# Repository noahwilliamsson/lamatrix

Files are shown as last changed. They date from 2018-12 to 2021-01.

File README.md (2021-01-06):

<!-- START doctoc generated TOC please keep comment here to allow auto update -->
<!-- DON'T EDIT THIS SECTION, INSTEAD RE-RUN doctoc TO UPDATE -->
**Table of Contents**  *generated with [DocToc](https://github.com/thlorenz/doctoc)*

- [Animated LED matrix display](#animated-led-matrix-display)
    - [Building and deploying the MCU](#building-and-deploying-the-mcu)
        - [MicroPython](#micropython)
        - [Arduino](#arduino)
    - [Hardware](#hardware)
        - [LED matrix display](#led-matrix-display)
        - [MCUs](#mcus)
            - [WiPy 3.0 pinout](#wipy-30-pinout)
            - [Teensy 3.1/3.2 pinout](#teensy-3132-pinout)
        - [Raspberry Pi](#raspberry-pi)
    - [Wiring things up](#wiring-things-up)
        - [LED matrix](#led-matrix)
        - [Button](#button)
        - [Connecting second UART on Pycom module to Raspberry Pi](#connecting-second-uart-on-pycom-module-to-raspberry-pi)
        - [Remote power management for Raspberry Pi](#remote-power-management-for-raspberry-pi)
    - [Hacking](#hacking)
        - [On the serial protocol](#on-the-serial-protocol)
    - [Running the Python scripts](#running-the-python-scripts)
    - [Configuring the Raspberry Pi](#configuring-the-raspberry-pi)
        - [Optional steps](#optional-steps)
- [Credits](#credits)

<!-- END doctoc generated TOC please keep comment here to allow auto update -->

# Animated LED matrix display

This is a project to drive a 32x8 or 16x16 LED matrix based on the popular WS2812 RGB LEDs using a microcontroller running [MicroPython](https://micropython.org).  There is experimental support for allowing a more powerful host computer (e.g. a Raspberry Pi Zero W) to remotely control a microcontroller without WiFi (e.g. a Teensy 3.x) and the display connected to it over USB serial.  Low FPS video of a standalone Pycom LoPy 1 development board cycling through the scenes:

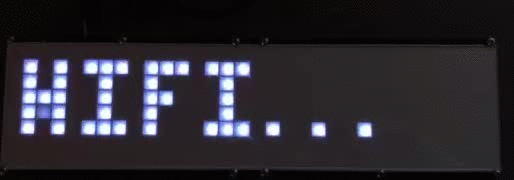
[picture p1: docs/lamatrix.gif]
LED matrix animated


Static picture with clock scene.  For some reason the colors aren't captured as vidvid as they are in real life.

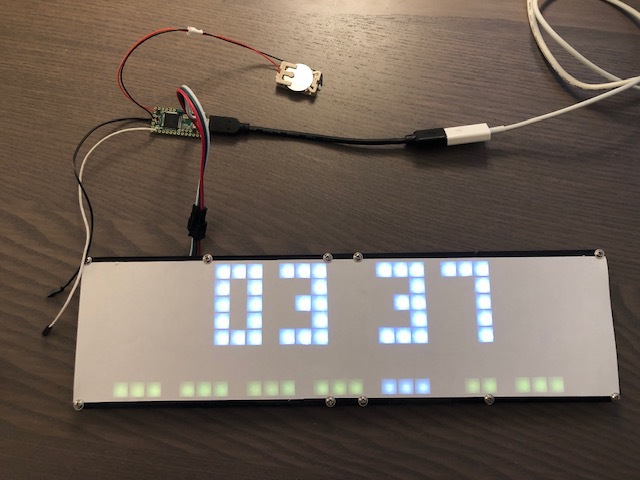
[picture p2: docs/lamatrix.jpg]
LED matrix with clock scene


Features:

- clock (time, date and weekday)
- weather
- random animations
- button inputs
- [config](config.json) file in JSON
- multiple WiFi networks can be configured

Primary development has been made on [Pycom](https://www.pycom.io)'s development boards, including the (obsolete) LoPy 1 and the newer WiPy 3.  There is also an Arduino [sketch](ArduinoSer2FastLED/ArduinoSer2FastLED.ino) for Teensy 3.1/3.2 boards that implements a custom serial protocol that is spoken by the host software ([main.py](main.py) and [arduinoserialhal.py](arduinoserialhal.py)) that allows the LED matrix to be remotely controlled.

**Update 2021**: If you want to use this with a Raspberry Pi instead of an MCU running MicroPython, see the issue [Using Raspberry PI directly to 8 x 32 not working?](https://github.com/noahwilliamsson/lamatrix/issues/1).

## Building and deploying the MCU

### MicroPython

[Connect](https://docs.pycom.io/gettingstarted/connection/) your Pycom module to your computer via USB (or 3.3v serial).  Open a serial connection to the module and [configure WiFi](https://docs.pycom.io/tutorials/all/wlan.html) in the REPL like this:

    from network import WLAN
    wlan = WLAN(mode=WLAN.STA)
    wlan.connect('yourSSID', auth=(WLAN.WPA2, 'yourPassword'))

Connect to the Pycom module's [native FTP server](https://docs.pycom.io/gettingstarted/programming/ftp.html) and login with `micro` / `python`.

Update [config.json](config.json) with your wireless SSID and password.

Upload the following files to `/flash`:

- [config.json](config.json)
- [main.py](main.py)

Upload the following files to `/flash/lib`:

- [animationscene.py](animationscene.py)
- [bootscene.py](bootscene.py)
- [clockscene.py](clockscene.py)
- [demoscene.py](demoscene.py)
- [firescene.py](firescene.py)
- [weatherscene.py](weatherscene.py)
- [icon.py](icon.py)
- [ledmatrix.py](ledmatrix.py)
- [pycomhal.py](pycomhal.py)
- [renderloop.py](renderloop.py)
- [urequests.py](urequests.py) (needed by `weatherscene.py`)
- [ws2812.py](ws2812.py) (needed by `pycomhal.py`)

Create a new directory under `/flash/icons` and upload any animation icons referenced in [config.json](config.json) (see [icons/README.md](icons/README.md) for details).

Create a new directory under `/flash/weather` and upload animated weather icons (see [weather/README.md](weather/README.md) for details).

Next, you'll want to read [Wiring things up](#wiring-things-up).

### Arduino

The host-side Python code expects to be able to talk to the microcontroller over a serial protocol (running on top of USB serial).  Software that speaks this special protocol and can talk to the LED matrix needs to be loaded onto the microcontroller.

Assuming you have an MCU which is supported by Arduino, try:

1. Download the latest version of Arduino
2. In the _Library manager_, found via the menu entry _Tools > Manage Libraries..._, search for `fastled` and install the package
3. If you have a Teensy 3.x MCU, install the Arduino software add-on Teensyduino from https://www.pjrc.com/teensy/td_download.html
4. Connect the MCU to your computer using an USB cable
5. Open the Arduino sketch (project)
6. Setup the board under the _Tools_ menu, e.g. for a Teensy board:
  - Board: `Teensy 3.2 / 3.1`
  - Port: `/dev/tty.usbmodem575711` (exact path might depend on the specific board and OS)
7. Build (compile) the sketch via the menu entry _Sketch > Verify/Compile_
8. Upload the newly built sketch to the MCU via the menu entry _Sketch > Upload_

## Hardware

### LED matrix display

On popular auction sites there are 8x8, 8x32 and 16x16 flexible LED matrix displays with WS2812 LEDs if you search for e.g. `LED Matrix WS2812 5050 flexible`:

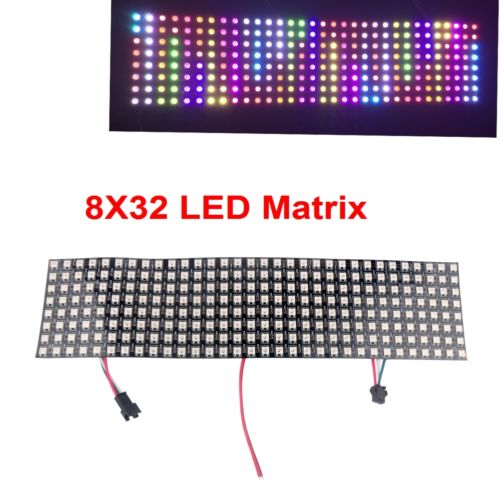
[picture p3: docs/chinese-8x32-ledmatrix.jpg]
.

Price: €35-45

For the 8x32 variant, you can 3D print a frame from these objects:

- [32x8 LED Matrix grid for diffuser](https://www.thingiverse.com/thing:1903744)
- [3d-parts/lamatrix.scad](3d-parts/lamatrix.scad) (customize it in [OpenSCAD](https://www.openscad.org/downloads.html), hit Render (F6) and export it as STL)

For diffusing the light emitted by the LEDS a paper works suprisingly well if it's tightly held to the grid.

### MCUs

- [WiPy 3.0](https://pycom.io/product/wipy-3-0/) and an [Expansion Board 3.0](https://pycom.io/product/expansion-board-3-0/) for easy programming via USB
  - ESP-32 platform, 520kBytes SRAM + 4MBytes (external) pSRAM, 8MBytes flash, 802.11b/g/n 16Mbps WiFi
  - Price: €20-25
  - Docs and pinout: https://docs.pycom.io/datasheets/development/wipy3
  - Expansion Board (€20-25) docs: https://docs.pycom.io/datasheets/boards/expansion3
- [https://www.pjrc.com/teensy/](Teensy) (for Teensy 3.1/3.2, solder a 32.768kHz crystal to allow for [time-keeping via a battery](https://www.pjrc.com/teensy/td_libs_Time.html))
  - Teensy 3.2: ARM Cortex-M4 72MHz, 64kBytes SRAM, 256kBytes flash, RTC (requires 32kHz crystal and a 3V battery)
  - Price: €20-25
  - Specs and pinout: https://www.pjrc.com/teensy/teensyLC.html

Both alternatives support both Arduino and MicroPython.

NOTE: it seems that hardware flow control between pyserial and the Pycom modules (e.g. WiPy, LoPy) doesn't work properly for some reason.  This results in the host overwhelming the microcontroller with data, leading to data loss in the serial protocol which in turn messes up what is displayed on the LED matrix.  The Teensy 3.x boards work without problems however.

#### WiPy 3.0 pinout

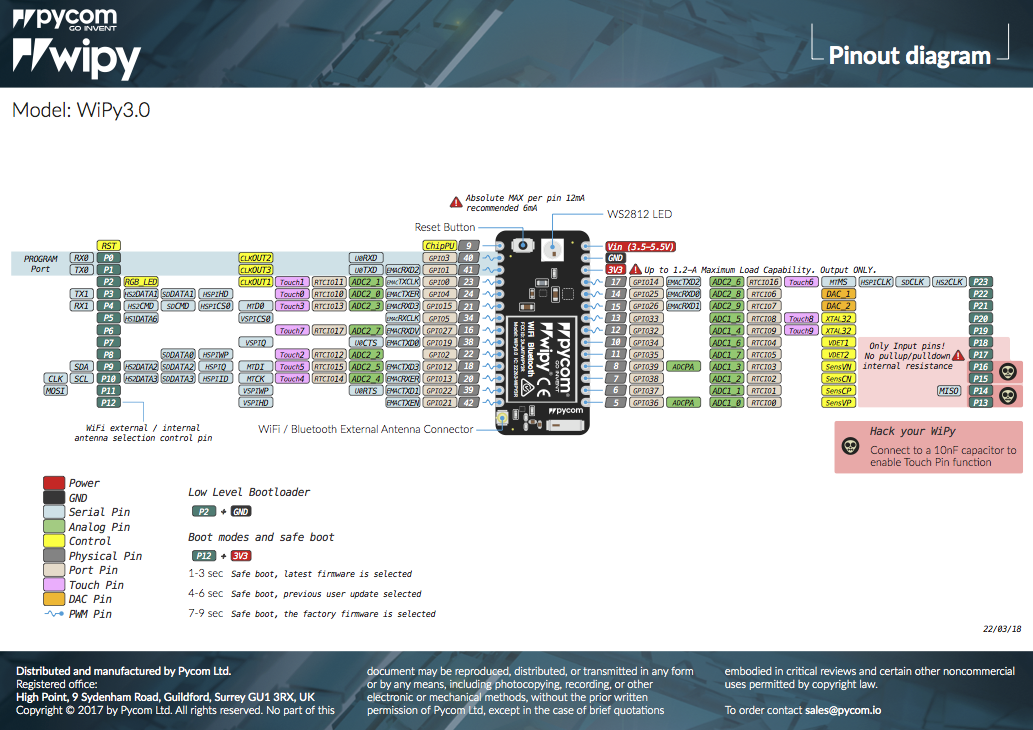
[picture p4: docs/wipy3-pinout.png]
WiPy 3.0 pinout


Source: https://docs.pycom.io/datasheets/development/wipy3.html

#### Teensy 3.1/3.2 pinout

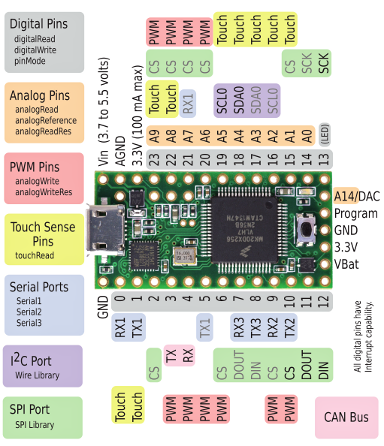
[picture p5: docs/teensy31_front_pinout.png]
Teensy 3.1/3.2 pinout


Source: https://www.pjrc.com/teensy/teensyLC.html

### Raspberry Pi

Newer Raspberry Pi computers have a non-populated RUN pin (marked with a square) that, if tied to ground, will reset the Pi's CPU.  See this answer on [What are the RUN pin holes on Raspberry Pi 2?](https://raspberrypi.stackexchange.com/questions/29339/what-are-the-run-pin-holes-on-raspberry-pi-2/33945#33945).

Since there is a 10k pull-up resistor connected to this pin, the Pi will turn on again when this pin is no longer tied to ground.  The drawback is of course that resetting the CPU leads to an unclean shutdown of the Pi, which in turn might lead to SD card corruption.

A Raspberry Pi which has previously been shutdown using e.g. `sudo poweroff` can be brought back to life by temporarily grounding GPIO 5 (a.k.a BCM 3 a.k.a SCL).  With the help of a small Python script running in the background we can make GPIO 5 an input pin and watch for level changes.  If this pin becomes LOW (i.e. tied to ground) we can initiate a clean shutdown with `sudo systemctl poweroff --force`.

Example from [raspberry-pi/gpio-shutdown.py](raspberry-pi/gpio-shutdown.py):

```python
#!/usr/bin/python
#
# Watch the board pin number 5 for level changes and initiate a power-off
# when this pin goes low.
#
from RPi import GPIO
from subprocess import call

# https://pinout.xyz/pinout/i2c
pin = 5  # a.k.a BCM 3 a.k.a SCL

GPIO.setmode(GPIO.BOARD)
GPIO.setup(pin, GPIO.IN)
GPIO.wait_for_edge(pin, GPIO.FALLING)
print('GPIO 5 dropped to low, initiating poweroff')
call(["/bin/systemctl","poweroff","--force"])
```

## Wiring things up

To the extent possible I've attempted to choose the same set of board pins on both MCUs (microcontrollers).

A short note on pin mappings:

- physical pin numbering refer to the chip's physical pins
- GPIO pin number refer to the chip's internal GPIO pin numbering (e.g. `GPIO22` as shown in pinout mappings)
- board pin numbering refer to the pins as made available on the PCB, with pin 0 or 1 often being in the top left corner after excluding any power/ground/reset pins
- pin ID as mapped in firmware, e.g. _digital pin_ number 10 or _P10_ (as shown in pinout mappings)

### LED matrix

Connect the display like this:

    LED matrix:  5V --> MCU: Vin pin (voltage in)
    LED matrix: GND --> MCU: GND pin
    LED matrix: DIN --> MCU: digital pin 6 on Teensy; P11 (a.k.a GPIO22) on Pycom module

### Button

Connect the buttons like this:

    Left button pin 1 --> MCU: digital pin 9 on Teensy; P9 (a.k.a. GPIO21) pin on Pycom module
    Left button pin 2 --> MCU: GND pin
    Right button pin 1 --> MCU: digital pin 10 on Teensy; P10 (a.k.a. GPIO13) pin on Pycom module
    Right button pin 2 --> MCU: GND pin

### Connecting second UART on Pycom module to Raspberry Pi

To connect the Pycom module's (e.g. WiPy) second UART (3.3V serial port) to the Raspberry Pi's UART, connect:

    Raspberry Pi: board pin  8 (TXD) --> MCU: P4 (a.k.a RX1 a.k.a GPIO15) on Pycom module
    Raspberry Pi: board pin 10 (RXD) --> MCU: P3 (a.k.a TX1 a.k.a GPIO4) on Pycom module
    Raspberry Pi: board pin  6 (GND) --> MCU: GND pin

NOTE: Raspberry Pi modules with built-in WiFi/Bluetooth needs the following line in `/boot/config.txt` to [free up the TXD/RXD pins](https://www.raspberrypi.org/documentation/configuration/uart.md):

    dtoverlay=pi3-disable-bt

Running `screen /dev/serial0 115200` on the Raspberry Pi should now allow you to see data sent from the MCU's second UART.

### Remote power management for Raspberry Pi

To let the MCU manage the Raspberry Pi's power, connect:

    Raspberry Pi: board pin 5 (a.k.a SCL) --> MCU: digital pin 8 on Teensy; P8 (a.k.a GPIO2) on Pycom module
    Raspberry Pi: board pin 6 (a.k.a GND) --> MCU: GND pin

## Hacking

In short:

- everything starts in [main.py](main.py)
- after initializing things, `main.py` hands over control to [renderloop.py](renderloop.py) which consumes _scenes_ (e.g. a [clock](clockscene.py) scene, a [weather](weatherscene.py) scene, ..)
- a framebuffer wrapper around the LED matrix display is in [ledmatrix.py](ledmatrix.py)
- the framebuffer wrapper does low-level display operations via a HAL (hardware abstraction layer)
  - on the host-side this is implemented in [arduinoserialhal.py](arduinoserialhal.py)
  - on the host-side this file pretty much opens a serial port and speaks a custom protocol to command the microcontroller to do things
- on the microcontroller-side the custom protocol is implemented in:
  - [ArduinoSer2FastLED.ino](ArduinoSer2FastLED/ArduinoSer2FastLED.ino) for devices running Arduino
  - [pycomhal.py](pycomhal.py) for Pycom devices running MicroPython

To add a new scene, create a Python module (e.g. `demoscene.py`) like this:

```python
from pixelfont import PixelFont

class DemoScene:
    """This module implements an example scene with a traveling pixel"""

    def __init__(self, display, config):
        """
        Initialize the module.
        `display` is saved as an instance variable because it is needed to
        update the display via self.display.put_pixel() and .render()
        """
        self.display = display
        self.intensity = 32
        self.x_pos = 0
        self.text = 'example'
        if not config:
            return
        if 'intensity' in config:
            self.intensity = int(round(config['intensity']*255))

    def reset(self):
        """
        This method is called before transitioning to this scene.
        Use it to (re-)initialize any state necessary for your scene.
        """
        self.x_pos = 0
        print('DemoScene: here we go')

    def input(self, button_state):
        """
        Handle button input
        """
        print('DemoScene: button state: {}'.format(button_state))
        return 0  # signal that we did not handle the input

    def set_intensity(self, value=None):
        if value is not None:
            self.intensity -= 1
            if not self.intensity:
                self.intensity = 16
        return self.intensity

    def render(self, frame, dropped_frames, fps):
        """
        Render the scene.
        This method is called by the render loop with the current frame number,
        the number of dropped frames since the previous invocation and the
        requested frames per second (FPS).
        """

        if (frame % fps) == 0:
            # Only update pixel once every second
            return True

        display = self.display
        intensity = self.intensity

        dot_x, dot_y = self.x_pos, 0
        text_x, text_y = 2, 2
        color = intensity
        display.clear()
        display.put_pixel(dot_x, dot_y, color, color, color >> 1)
        display.render_text(PixelFont, self.text, text_x, text_y, self.intensity)
        display.render()

        self.x_pos += 1
        if self.x_pos == display.columns:
            return False   # signal that our work is done

        return True   # we want to be called again
```

Then open [main.py](main.py) and locate the following line:

```python
r = RenderLoop(display, config)
```

Below it, create an instance of your module and call `RenderLoop.add_scene()` to add it to the list of scenes.  If your module is named `demoscene.py` and implements the `DemoScene` class it should look something like this:

```python
if 'Demo' in config:
    from demoscene import DemoScene
    scene = DemoScene(display, config['Demo'])
    r.add_scene(scene)
```

You should also add a `"Demo": {},` block to the config file `config.json`.  Store any settings your scene needs here.

With these steps completed, the scene's `render()` method should now eventually be called when you run the host-side software (e.g. `python main.py`).  The method should return `True` until you're ready to hand over control to the next scene, in which case you signal this by returning `False`.

### On the serial protocol

Because of the limited amount of memory available on MCU it was initially decided to use a more powerful computer to render things on the LED matrix display.  The most natural way of connecting a MCU and a host computer is to use the serial interface available on many popular MCUs, and thus a serial protocol was born.

To add new functionality to the serial protocol, ensure that you make the necessary updates in:

- the MCU implementation on the Arduino side, in and around `loop()`
- the MCU implementation on the MicroPython side, in `pycomhal.py`
- the host computer implementation, in `arduinoserialhal.py`

## Running the Python scripts

For Debian/Ubuntu derived Linux systems, try:

```bash
sudo apt install -y python-requests python-serial
```

On macOS, install pyserial (macOS already ships the requests module):

```bash
sudo -H easy_install serial
```

NOTE: There are known issues with hardware flow control and the driver/chip used in the Pycom modules (e.g. WiPy, LoPy).  This causes the host side scripts to overwhelm the microcontroller with data.  There do not appear to be any such issues with the Teensy on macOS.  There are no known issues with either module with recent Linux distributions, including Raspbian.

Connect the LED matrix to the microcontroller and then connect the microcontroller to your computer (via USB).  You should now be able to command the microcontroller to drive the display with:

```bash
python main.py
```

NOTES:

- The animation scene expects animated icons from a third-party source.  See the [icons/README.md](icons/README.md) for details on how to download them.
- The weather scene expects animated icons from a third-party source.  See the [weather/README.md](weather/README.md) for details on how to download them.

## Configuring the Raspberry Pi

If you want to run the Python scripts on the Raspberry Pi, install the necessary Python packages:

```bash
sudo apt install -y python-requests python-serial
# On Raspberry Pi Zero importing the Python `requests` package takes 20+ seconds
# if the python-openssl package is installed (default on Raspbian).
# https://github.com/requests/requests/issues/4278
#
# Uninstall it to speed up loading of `weatherscene.py`
sudo apt purge -y python-openssl
```

Install the support files:

- copy [gpio-shutdown.service](raspberry-pi/gpio-shutdown.service) into `/etc/systemd/system/`
- copy [lamatrix.service](raspberry-pi/lamatrix.service) into `/etc/systemd/system/`

Assuming you've cloned this repo at `/home/pi/lamatrix`, proceed as follows:

```bash
sudo apt install -y python-requests python-serial
cd ~/lamatrix

mkdir -p icons weather
# Download animated icons per the instructions in icons/README.md
# Download animated weather icons per the instructions in icons/README.md

# Install and start services
chmod +x main.py raspberry-pi/gpio-shutdown.py
sudo cp raspberry-pi/gpio-shutdown.service /etc/systemd/system
sudo cp raspberry-pi/lamatrix.service /etc/systemd/system
sudo systemctl daemon-reload
sudo systemctl enable gpio-shutdown.service lamatrix.service
sudo systemctl start gpio-shutdown.service lamatrix.service
```

NOTE: If you're not running under the `pi` user or have placed the files somewhere else than `/home/pi/lamatrix` you will have to update the `ExecPath=`, `User=` and `Group=` attributes in the `.service` files accordingly.

Your Raspberry Pi will now poweroff when board pin number 5 (a.k.a BCM 3 a.k.a SCL) goes LOW (e.g. is temporarily tied to ground).  The shutdown process takes 10-15 seconds.  The Pi can be powered up by again temporarily tying the pin to ground again.

To actually make use of the remote shutdown and reboot feature you need to physically wire the microcontroller to the Raspberry Pi.  Connect the microcontroller's `GND` (ground) to one of the `GND` pins on the Raspberry Pi.  Connect pin 14 (see `HOST_SHUTDOWN_PIN` in [ArduinoSer2FastLED.ino](ArduinoSer2FastLED/ArduinoSer2FastLED.ino)) on the microcontroller to the Raspberry Pi's [BCM 3 a.k.a SCL](https://pinout.xyz/pinout/i2c).

### Optional steps

If you're running a headless Raspberry Pi you can reduce the boot time by a few seconds with:

```bash
sudo apt-get purge -y nfs-common libnfsidmap2 libtirpc1 rpcbind python-openssl
grep -q boot_delay /boot/config.txt || echo boot_delay=0 |sudo tee -a /boot/config.txt
sudo systemctl disable dphys-swapfile exim4 keyboard-setup raspi-config rsyslog
```

(the `python-openssl` package slows down the import of the `python-requests` package: https://github.com/requests/requests/issues/4278)

# Credits

Several animations in the form of `.json` files were backed up from LaMetric's developer API.  Credit goes to the original authors of these animations.

The [urequests.py](urequests.py) file is a slightly modified copy from [micropython/micropython-lib](https://github.com/micropython/micropython-lib).

The [ws2812.py](ws2812.py) file, a MicroPython implementation for controlling WS2812 LEDs, is based on work published on [JanBednarik/micropython-ws2812](https://github.com/JanBednarik/micropython-ws2812).

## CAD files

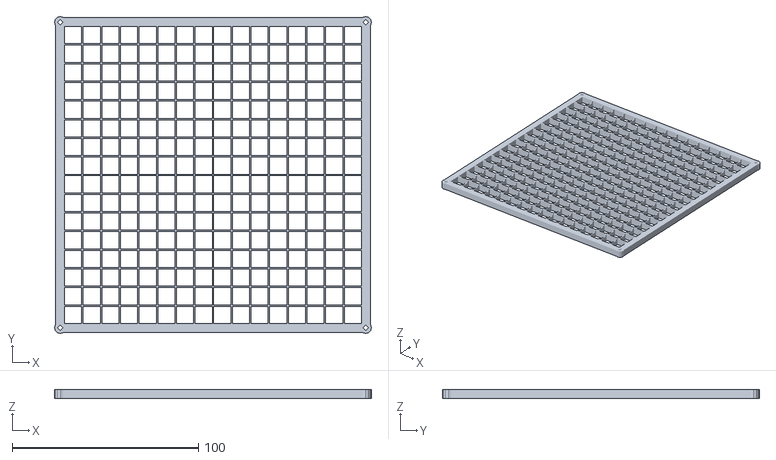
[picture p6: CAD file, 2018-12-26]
3d-parts/squareDiffuserGrid16x16.stl
170.0 x 170.0 x 5.00

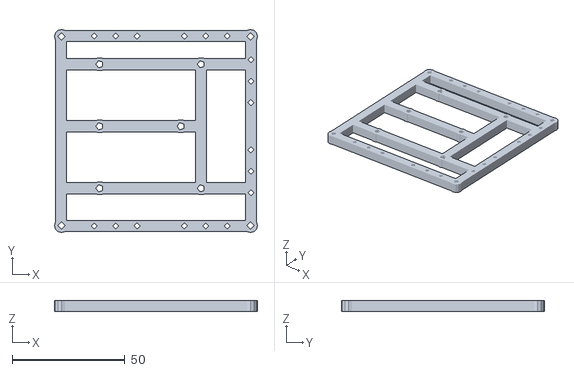
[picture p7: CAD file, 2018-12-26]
3d-parts/squareBacksideFrame8x8.stl
90.0 x 90.0 x 5.00

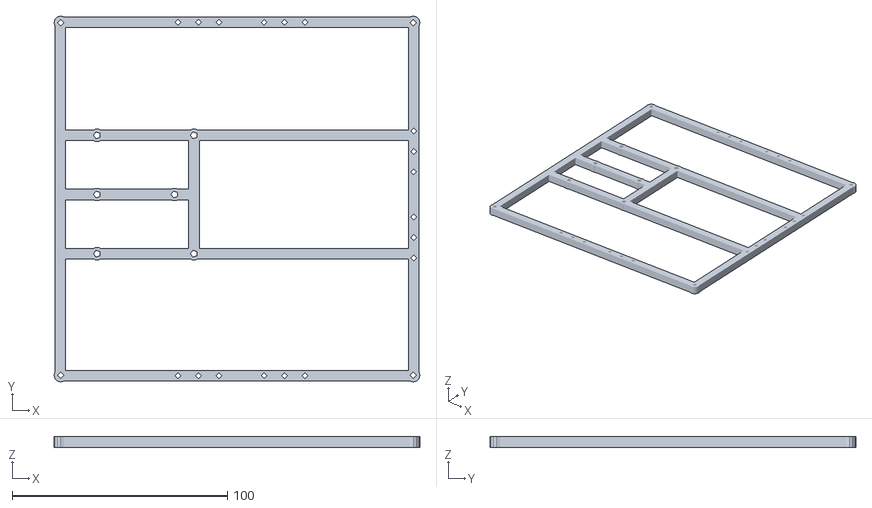
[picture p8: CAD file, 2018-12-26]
3d-parts/squareBacksideFrame16x16.stl
170.0 x 170.0 x 5.00

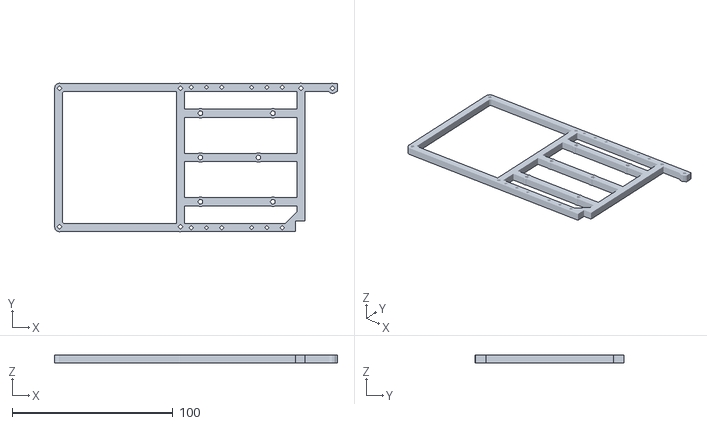
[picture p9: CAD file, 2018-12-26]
3d-parts/backsideFrame32x8.stl
175.8 x 92.4 x 5.00

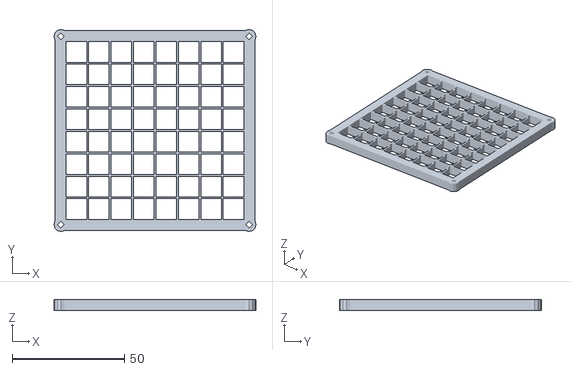
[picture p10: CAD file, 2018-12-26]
3d-parts/squareDiffuserGrid8x8.stl
90.0 x 90.0 x 5.00

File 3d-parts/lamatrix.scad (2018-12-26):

/**
 * Things to contain flexible LED matrix displays
 *
 * Hit F6 to render the part and then export it to STL.
 * Load in your favorite slicer and print it.
 *
 *   -- noah@hack.se, 2018
 */

/**
 * Combine with '32x8 LED Matrix grid for diffuser'
 * https://www.thingiverse.com/thing:1903744
 *
 * Additional hardware: 12x 2.6x10mm plastic screws
 */
backsideFrame32x8();

/**
 * Parts for 8x8 or 16x16 LED matrices
 *
 * Comment the above part by prefixing the module call with an asterisk
 * and then uncomment one of the parts below.  Hit F6 to render and then
 * export as STL.
 *
 */
*squareDiffuserGrid(16); // 16x16 LED matrix
*squareBacksideFrame(16);
*squareDiffuserGrid(8); // Uncomment for 8x8 LED matrix
*squareBacksideFrame(8); // 16x16 LED matrix


// Config
M2hole=1.9;
M2_3hole=2.2;
M3hole=2.7;


// Helper routine
module polyhole(d, h) {
    n = max(round(2 * d),3);
    rotate([0,0,180])
        cylinder(h = h, r = (d / 2) / cos (180 / n), $fn = n);
}


module squareDiffuserGrid(pixels=16) {
	xRows=pixels;
	yRows=pixels;
	cellSize=10;
	thickness=5;
	cylSize=6;
	gridThickness=0.8;
	componentLength=6;
	componentHeight=1.25;

	difference() {
		union() {
			// Grid
			for(x=[1:xRows-1]) {
				tmp = x != xRows/2? gridThickness: gridThickness; //*2
				translate([x*cellSize-tmp/2, 0, 0])
					cube([tmp, cellSize*yRows, thickness]);
			}
			for(y=[1:yRows-1]) {
				tmp = y != yRows/2? gridThickness: gridThickness; //*2
				translate([0, y*cellSize-tmp/2, 0])
					cube([cellSize*xRows, tmp, thickness]);
			}
			// Corners
			for(x=[0,1]) {
				for(y=[0,1]) {
					translate([-cylSize/PI+x*(xRows*cellSize+2*cylSize/PI), -cylSize/PI+y*(yRows*cellSize+2*cylSize/PI), 0])
						polyhole(d=cylSize, h=thickness);
				}
			}
			// Outer joining the corners and the grid
			for(i=[0,1]) {
				// X walls
				translate([-cylSize/2, gridThickness/2-thickness+i*(cellSize*yRows+thickness-gridThickness), 0])
					cube([cylSize+cellSize*xRows, thickness, thickness]);
				// Y walls
				translate([gridThickness/2-thickness+i*(cellSize*xRows+thickness-gridThickness), -cylSize/2, 0])
					cube([thickness, cylSize+cellSize*yRows, thickness]);
			}
		}
		// Make room for external components
		for(y=[1:yRows]) {
			for(x=[1:xRows-1]) {
				translate([x*cellSize-gridThickness,y*cellSize-cellSize/2-componentLength/2,thickness-componentHeight])
					cube([gridThickness*2,componentLength,componentHeight+.5]);
			}
		}
		// Screw holes corners
		for(x=[0,1])
			for(y=[0,1])
				translate([-cylSize/PI+x*(xRows*cellSize+2*cylSize/PI), -cylSize/PI+y*(yRows*cellSize+2*cylSize/PI), -.5])
					polyhole(d=M2_3hole, h=thickness+1);
	}
}


module squareBacksideFrame(pixels=16) {
	xRows=pixels;
	yRows=pixels;
	cellSize=10;
	thickness=5;
	cylSize=6;
	gridThickness=0.8;
	componentLength=6;
	componentHeight=1.25;
	pcbHoleDistance=36;
	usbHoleDistance=9;
	expansionBoardHoleDistanceX=45;
	expansionBoardHoleDistanceY=55;

	height=(cellSize*yRows+thickness-gridThickness);
	width=(cellSize*xRows+thickness-gridThickness);

	difference() {
		union() {
			// Corners
			for(x=[0,1]) {
				for(y=[0,1]) {
					translate([-cylSize/PI+x*(xRows*cellSize+2*cylSize/PI), -cylSize/PI+y*(yRows*cellSize+2*cylSize/PI), 0])
						polyhole(d=cylSize, h=thickness);
				}
			}
			// Outer joining the corners and the grid
			for(i=[0,1]) {
				// X walls
				translate([-cylSize/2, gridThickness/2-thickness+i*(cellSize*yRows+thickness-gridThickness), 0])
					cube([cylSize+cellSize*xRows, thickness, thickness]);
				// Y walls
				translate([gridThickness/2-thickness+i*(cellSize*xRows+thickness-gridThickness), -cylSize/2, 0])
					cube([thickness, cylSize+cellSize*yRows, thickness]);
			}
			// Stabilizator Pycom expansion board
			for(i=[-1,1]) {
				translate([0, height/2-thickness/2+i*expansionBoardHoleDistanceY/2,0])
					cube([width, thickness, thickness]);
				// Screw holes
				translate([15, height/2-i*expansionBoardHoleDistanceY/2,0])
					cylinder(d=6, h=thickness);
				translate([15, height/2-i*expansionBoardHoleDistanceY/2,0])
					cylinder(d=6, h=thickness);
				translate([15+expansionBoardHoleDistanceX, height/2-i*expansionBoardHoleDistanceY/2,0])
					cylinder(d=6, h=thickness);
				translate([15+expansionBoardHoleDistanceX, height/2-i*expansionBoardHoleDistanceY/2,0])
					cylinder(d=6, h=thickness);
			}
			// Adafruit Perma-Proto stabilizator and screw holes
			translate([0, height/2-thickness/2,0])
				cube([15+expansionBoardHoleDistanceX, thickness, thickness]);
			translate([15+expansionBoardHoleDistanceX-thickness/2, height/2-expansionBoardHoleDistanceY/2, 0])
				cube([thickness, expansionBoardHoleDistanceY, thickness]); // Join with stabilizator for Pycom exp board
			translate([15, height/2,0])
				cylinder(d=6, h=thickness);
			translate([15+pcbHoleDistance, height/2,0])
				cylinder(d=6, h=thickness);
		}
		// Screw holes corners
		for(x=[0,1])
			for(y=[0,1])
				translate([-cylSize/PI+x*(xRows*cellSize+2*cylSize/PI), -cylSize/PI+y*(yRows*cellSize+2*cylSize/PI), -.5])
					polyhole(d=M2_3hole, h=thickness+1);
		// SS-5GL micro switch screw holes
		for(y=[0,1]) {
			for(x=[-20,20]) {
				translate([x+width/2-9.5, y*height-thickness/2+gridThickness/2, -.5])
					polyhole(d=M2hole, h=thickness+1);
				translate([x+width/2, y*height-thickness/2+gridThickness/2, -.5])
					polyhole(d=M2hole, h=thickness+1);
				translate([x+width/2+9.5, y*height-thickness/2+gridThickness/2, -.5])
					polyhole(d=M2hole, h=thickness+1);
			}
		}
		for(y=[-20,20]) {
			translate([cellSize*xRows+thickness/2-gridThickness/2, y+height/2-9.5, -.5])
				polyhole(d=M2hole, h=thickness+1);
			translate([cellSize*xRows+thickness/2-gridThickness/2, y+height/2, -.5])
				polyhole(d=M2hole, h=thickness+1);
			translate([cellSize*xRows+thickness/2-gridThickness/2, y+height/2+9.5, -.5])
				polyhole(d=M2hole, h=thickness+1);
		}
		// Permaproto screw holes
		translate([15, height/2, -.5])
			polyhole(d=M3hole, h=thickness+2+1);
		translate([15+pcbHoleDistance, height/2, -.5])
			polyhole(d=M3hole, h=thickness+2+1);
		// Pycom expansion board screw holes
		for(i=[-1,1]) {
			translate([15, height/2-i*expansionBoardHoleDistanceY/2, -.5])
				polyhole(d=M3hole, h=thickness+2+1);
			translate([15, height/2-i*expansionBoardHoleDistanceY/2, -.5])
				cylinder(d=M3hole, h=thickness+2+1);
			translate([15+expansionBoardHoleDistanceX, height/2-i*expansionBoardHoleDistanceY/2, -.5])
				polyhole(d=M3hole, h=thickness+2+1);
			translate([15+expansionBoardHoleDistanceX, height/2-i*expansionBoardHoleDistanceY/2, -.5])
				polyhole(d=M3hole, h=thickness+2+1);
		}
	}
}


module backsideFrame32x8() {
	thickness=5;
	cylSize=6.25;
	screwXDistance=75;
	screwYDistance=86;
	// Extra feature: PCB mounting bars
	pcbHoleDistance=36;
	usbHoleDistance=9;
	expansionBoardHoleDistanceX=45;
	expansionBoardHoleDistanceY=55;

	difference() {
		union() {
			// 2x3 screw holes
			for(x=[0,1,2]) {
				translate([x*screwXDistance, 0, 0])
					polyhole(d=cylSize, h=thickness);
				translate([x*screwXDistance, screwYDistance, 0])
					polyhole(d=cylSize, h=thickness);
			}
			// Stabilizator
			translate([2*screwXDistance-8,-cylSize/2,0])
				rotate([0,0,45])
					cube([14,5,thickness]);
			translate([2*screwXDistance+19.5, screwYDistance, 0])
				polyhole(d=cylSize, h=thickness);

			// X beams to joins screw holes
			for(x=[0,1]) {
				translate([x*screwXDistance, -cylSize/2, 0])
					cube([screwXDistance, thickness, thickness]);
				translate([x*screwXDistance, cylSize/2-thickness+screwYDistance, 0])
					cube([screwXDistance, thickness, thickness]);
			}
			// Stabilizator
			translate([2*screwXDistance, cylSize/2-thickness+screwYDistance, 0])
				cube([19.5+cylSize/2, thickness, thickness]);

			// Y beam to join screw holes
			translate([-cylSize/2, 0, 0])
				cube([thickness, 86, thickness]);
			for(x=[1,2]) {
				translate([x*screwXDistance-thickness/2, 0, 0])
					cube([thickness, screwYDistance, thickness]);
			}
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

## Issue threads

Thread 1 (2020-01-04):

Using Raspberry PI directly to 8 x 32 not working?

evanjmg, 2020-01-04:
Hi, thank you so much for this LED text example! I'm a total noob but got my [8 row x 32 columns BTF - 256 pixels](https://www.amazon.com/BTF-LIGHTING-0-24ft0-96ft-Flexible-Individually-addressable/dp/B01DC0IPVU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) working with this [other tutorial ](https://tutorials-raspberrypi.com/connect-control-raspberry-pi-ws2812-rgb-led-strips/)to display animated rainbows etc. However, I can't seem to get anything running with your code - I get the following port error below. Did I miss a step? Thank you for such a detailed readme  - I've followed all the python setup and am using the pin setup from the other tutorial above.

```
pi@raspberrypi:~/lamatrix $ python main.py
SerialProtocol: opening port /dev/ttyACM0 @ 115200 baud
Traceback (most recent call last):
  File "main.py", line 67, in <module>
    driver = HAL(config)
  File "/home/pi/lamatrix/arduinoserialhal.py", line 23, in __init__
    self.reset()
  File "/home/pi/lamatrix/arduinoserialhal.py", line 44, in reset
    self.ser = serial.Serial(self.port, baudrate=self.baudrate, rtscts=True, timeout=0.1, write_timeout=0.5)
  File "/usr/lib/python2.7/dist-packages/serial/serialutil.py", line 240, in __init__
    self.open()
  File "/usr/lib/python2.7/dist-packages/serial/serialposix.py", line 268, in open
    raise SerialException(msg.errno, "could not open port {}: {}".format(self._port, msg))
serial.serialutil.SerialException: [Errno 2] could not open port /dev/ttyACM0: [Errno 2] No such file or directory: '/dev/ttyACM0'
```

noahwilliamsson, 2020-01-15:
Hi,

Unfortunately this project does not support driving the LED matrix from a Raspberry Pi alone.  Instead it's expected that the LED matrix is driven via micro controller that either supports MicroPython (e.g. PyCom devices) or the Arduino FastLED library (e.g. a Teensy).

The error message happens because the current code think it's running on the "host side" and expects to find a micro controller to talk to (using a special protocol) over a serial interface.  When the serial port wasn't available the code crashed.

Thanks for the link to the tutorial.  It seems they make use of https://github.com/jgarff/rpi_ws281x to generate the necessary signals to control the LEDs using existing hardware on the Raspberry Pi.  It also seems there are Python bindings available for this library: https://github.com/rpi-ws281x/rpi-ws281x-python.

I suppose it would be technically possible to implement the HAL (hardware abstraction layer) expected by this project on top of the rpi-ws281x-python library.  Something that would provide most of the methods as seen in https://github.com/noahwilliamsson/lamatrix/blob/master/upyhal.py.

You would then need to make some modifications to https://github.com/noahwilliamsson/lamatrix/blob/master/main.py to make it all work because currently it's a bit of a mess to detect if the code is running on the host side or on the MCU side.

willumpie82, 2021-01-06:
Hi, @evanjmg, did you manage to port this project to run the led matrix natively connected to the pi?

noahwilliamsson, 2021-01-06:
Hi @willumpie82, @evanjmg.  I just pushed two changes that should allow you to try this project on a Raspberry Pi (tested on a 3 model B+).

To try it out:

```bash
# Install dependencies
sudo apt install -y python-pip python-requests
sudo pip install rpi_ws281x

# Per the instructions on https://github.com/jgarff/rpi_ws281x#pwm
echo blacklist snd_bcm2835 | sudo tee /etc/modprobe.d/snd-blacklist.conf
echo hdmi_force_hotplug=1 | sudo tee -a /boot/config.txt
echo hdmi_force_edid_audio=1 | sudo tee -a /boot/config.txt
sudo reboot
# Wait for the Raspberry Pi to reboot
```

Next, clone this repo and download necessary resources:
```bash
git clone https://github.com/noahwilliamsson/lamatrix
cd lamatrix

# Download icons (see https://github.com/noahwilliamsson/lamatrix/tree/master/icons)
curl -o icons/game-brick.json https://developer.lametric.com/api/v1/dev/preloadicons?icon_id=1524
curl -o icons/game-invaders-1.json https://developer.lametric.com/api/v1/dev/preloadicons?icon_id=3405
curl -o icons/game-invaders-2.json https://developer.lametric.com/api/v1/dev/preloadicons?icon_id=3407
curl -o icons/game-tetris.json https://developer.lametric.com/api/v1/dev/preloadicons?icon_id=4007
curl -o icons/game-nintendo.json https://developer.lametric.com/api/v1/dev/preloadicons?icon_id=5038
curl -o icons/game-pacman-ghosts.json https://developer.lametric.com/api/v1/dev/preloadicons?icon_id=20117
curl -o icons/game-pingpong.json https://developer.lametric.com/api/v1/dev/preloadicons?icon_id=4075
curl -o icons/game-snake.json https://developer.lametric.com/api/v1/dev/preloadicons?icon_id=16036
curl -o icons/matrix.json https://developer.lametric.com/api/v1/dev/preloadicons?icon_id=653
curl -o icons/newyears.json https://developer.lametric.com/api/v1/dev/preloadicons?icon_id=9356
curl -o icons/tv-movie.json https://developer.lametric.com/api/v1/dev/preloadicons?icon_id=7862
# Convert JSON to a less verbose binary representation
scripts/convert-animation.py icons/*.json
rm icons/*.json

# Download weather icons (see https://github.com/noahwilliamsson/lamatrix/tree/master/weather)
curl -o weather/sunny.json https://developer.lametric.com/api/v1/dev/preloadicons?icon_id=1338
curl -o weather/sunny-with-clouds.json https://developer.lametric.com/api/v1/dev/preloadicons?icon_id=8756
curl -o weather/cloud-partly.json https://developer.lametric.com/api/v1/dev/preloadicons?icon_id=2286
curl -o weather/cloudy.json https://developer.lametric.com/api/v1/dev/preloadicons?icon_id=12019
curl -o weather/fog.json https://developer.lametric.com/api/v1/dev/preloadicons?icon_id=17056
curl -o weather/moon-stars.json https://developer.lametric.com/api/v1/dev/preloadicons?icon_id=16310
curl -o weather/rain-snow.json https://developer.lametric.com/api/v1/dev/preloadicons?icon_id=160
curl -o weather/rain.json https://developer.lametric.com/api/v1/dev/preloadicons?icon_id=72
curl -o weather/snow-house.json https://developer.lametric.com/api/v1/dev/preloadicons?icon_id=7075
curl -o weather/snowy.json https://developer.lametric.com/api/v1/dev/preloadicons?icon_id=2289
curl -o weather/thunderstorm.json https://developer.lametric.com/api/v1/dev/preloadicons?icon_id=11428
# Convert JSON to a less verbose binary representation
scripts/convert-animation.py weather/*.json
rm weather/*.json
```

Wire up the display's +5V, GND and DIN to the Raspberry Pi header pins 4 (5v Power), 6 (GND) and 12 (GPIO 18 PCM CLK) respectively (see https://pinout.xyz).

Finally, try running the code:

```bash
python main.py
```

willumpie82, 2021-01-06:
It works (Y) on my rpiZeroW I do have one challange and that is the rotation of my individual panales are rotated 90degr each.

I have CJMCU-8*8 panels from Ali, i'll rotate them

noahwilliamsson, 2021-01-06:
You could try to modify `LedMatrix.xy_to_phys()` to account for that: https://github.com/noahwilliamsson/lamatrix/blob/master/ledmatrix.py#L50-L76.

My particular 32x8 display is laid out in a zig-zag pattern with the first eight pixels starting at the top-left corner going down in the first column.  Pixels 9-16 start in the bottom of the second column going upwards.

The above mentioned method takes care of translating a (x,y) coordinate (with (0,0) being the top-left corner) in a grid of `columns` x `stride` to a physical pixel number.  These two numbers (32 and 8 respectively) are configured here in https://github.com/noahwilliamsson/lamatrix/blob/master/config.json#L19-L20.

HTH.

willumpie82, 2021-01-07:
Thanx for the hints,

I came up with a formula to calculate (verified in Excel), need to be extended to be more configurable, and input and outputs protected for invalid values

phys_addr =  ((x-1)%self.panelcolumn) + ((y-1)*self.panelcolumn) + (self.round_down((x-1)/self.panelcolumn) * self.panelcolumn * self.panelrow)

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

results in:
`Traceback (most recent call last):
  File "main.py", line 202, in <module>
    r.next_frame(button_state)
  File "/home/pi/lamatrix/renderloop.py", line 91, in next_frame
    loop_again = scene.render(self.frame, self.frame - self.prev_frame - 1, self.fps)
  File "/home/pi/lamatrix/demoscene.py", line 62, in render
    display.put_pixel(dot_x, dot_y, color, color, color >> 1)
  File "/home/pi/lamatrix/ledmatrix.py", line 117, in put_pixel
    offset = pixel*3
TypeError: unsupported operand type(s) for *: 'NoneType' and 'int'`

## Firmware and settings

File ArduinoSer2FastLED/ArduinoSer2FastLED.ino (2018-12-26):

/**
 * Firmware to control a LED matrix display
 * https://github.com/noahwilliamsson/lamatrix
 *
 *   -- noah@hack.se, 2018
 *
 */

#ifdef TEENSYDUINO
#include <TimeLib.h>
#endif
#include "FastLED.h"


#define HOST_SHUTDOWN_PIN 8
#define LEFT_BUTTON_PIN 9
#define RIGHT_BUTTON_PIN 10
#define NUM_LEDS 256

#ifdef TEENSYDUINO
#define FastLED_Pin 6
#else
#define FastLED_Pin 22
#endif


static void put_pixel(int, int, int);
static void render_clock(int);
#ifdef TEENSYDUINO
static time_t getTeensy3Time();
#endif


/**
 * Serial protocol
 */
enum {
  FUNC_RESET = 0,
  /* Initialize display with [pixels & 0xff, (pixels>>8) & 0xff] LEDs */
  FUNC_INIT_DISPLAY = 'i',
  /* Clear display: [dummy byte] */
  FUNC_CLEAR_DISPLAY = 'c',
  /* Update display: [dummy byte] */
  FUNC_SHOW_DISPLAY = 's',
  /* Put pixel at [pixel&0ff, (pixel >> 8) &0xff, R, G, B] */
  FUNC_PUT_PIXEL = 'l',
  /* Set time [t&0xff, (t >> 8) & 0xff, (t >> 16) & 0xff, (t >> 24) & 0xff] */
  FUNC_SET_RTC = '@',
  /* Automatically render time [enable/toggle byte] */
  FUNC_AUTO_TIME = 't',
  /* Suspend host for [seconds & 0xff, (seconds >> 8) & 0xff] */
  FUNC_SUSPEND_HOST = 'S',
};


/* Computed with pixelfont.py */
static int font_width = 4;
static int font_height = 5;
static char font_alphabet[] = " %'-./0123456789:?acdefgiklmnoprstwxy";
static unsigned char font_data[] = "\x00\x00\x50\x24\x51\x66\x00\x00\x60\x00\x00\x00\x42\x24\x11\x57\x55\x27\x23\x72\x47\x17\x77\x64\x74\x55\x47\x74\x71\x74\x17\x57\x77\x44\x44\x57\x57\x77\x75\x74\x20\x20\x30\x24\x20\x52\x57\x25\x15\x25\x53\x55\x73\x31\x71\x17\x13\x71\x71\x75\x27\x22\x57\x35\x55\x11\x11\x57\x77\x55\x75\x77\x75\x55\x75\x57\x17\x71\x35\x55\x17\x47\x77\x22\x22\x55\x77\x55\x25\x55\x55\x27\x02";

/* Global states */
int state = 0;
int debug_serial = 0;
/* Debug state issues */
int last_states[8];
unsigned int last_state_counter = 0;
/* Non-zero when automatically rendering the current time */
int show_time = 1;
/* Non-zero while the host computer is turned off */
time_t reboot_at = 0;
/* Accumulator register for use between loop() calls */
unsigned int acc;
unsigned int color;
CRGB leds[NUM_LEDS];


static volatile int g_button_state;
static int button_down_t;
static void button_irq_left(void) {
  int state = digitalRead(LEFT_BUTTON_PIN);

  if(state == HIGH) {
    /* Start counting when the circuit is broken */
    button_down_t = millis();
    return;
  }
  if(!button_down_t)
    return;

  int pressed_for_ms = millis() - button_down_t;
  if(pressed_for_ms > 1500)
    g_button_state = 4;
  else if(pressed_for_ms > 500)
    g_button_state = 2;
  else if(pressed_for_ms > 100)
    g_button_state = 1;

  button_down_t = 0;
}

static void button_irq_right(void) {
  int state = digitalRead(RIGHT_BUTTON_PIN);

  if(state == HIGH) {
    /* Start counting when the circuit is broken */
    button_down_t = millis();
    return;
  }
  if(!button_down_t)
    return;

  int pressed_for_ms = millis() - button_down_t;
  if(pressed_for_ms > 1500)
    g_button_state = 64;
  else if(pressed_for_ms > 500)
    g_button_state = 32;
  else if(pressed_for_ms > 100)
    g_button_state = 16;

  button_down_t = 0;
}


void setup() {
  Serial.begin(460800);

  /* Initialize FastLED library */
  FastLED.addLeds<NEOPIXEL, FastLED_Pin>(leds, NUM_LEDS);

  /* Configure pin used to shutdown Raspberry Pi (connected to GPIO5 on the Pi) */
  pinMode(HOST_SHUTDOWN_PIN, OUTPUT);
  digitalWrite(HOST_SHUTDOWN_PIN, HIGH);

  /* Configure pins for the buttons */
  pinMode(LEFT_BUTTON_PIN, INPUT_PULLUP);
  attachInterrupt(digitalPinToInterrupt(LEFT_BUTTON_PIN), button_irq_left, CHANGE);
  pinMode(RIGHT_BUTTON_PIN, INPUT_PULLUP);
  attachInterrupt(digitalPinToInterrupt(RIGHT_BUTTON_PIN), button_irq_right, CHANGE);

#ifdef TEENSYDUINO
  /* Initialize time library */
  setSyncProvider(getTeensy3Time);
  if (timeStatus() != timeSet) {
     Serial.println("Unable to sync with the RTC");
  }
  else {
     Serial.println("RTC has set the system time");
     show_time = 1;
  }
  Serial.printf("%04d-%02d-%02dT%02d:%02d:%02dZ\n", year(), month(), day(), hour(), minute(), second());
#endif
}


void loop() {
#ifdef TEENSYDUINO
  time_t now = getTeensy3Time();
#else
  int now = 0;
#endif

  int button_state = g_button_state;
  if(button_state) {
    g_button_state = 0;

    if(button_state & 1)
      Serial.println("LEFT_SHRT_PRESS");
    else if(button_state & 2)
      Serial.println("LEFT_LONG_PRESS");
    else if(button_state & 4)
      Serial.println("LEFT_HOLD_PRESS");
    if(button_state & 16)
      Serial.println("RGHT_SHRT_PRESS");
    else if(button_state & 32)
      Serial.println("RGHT_LONG_PRESS");
    else if(button_state & 64)
      Serial.println("RGHT_HOLD_PRESS");
  }

  if(reboot_at && now >= reboot_at) {
    /* Restart host computer */
    digitalWrite(HOST_SHUTDOWN_PIN, LOW);
    delay(1);
    digitalWrite(HOST_SHUTDOWN_PIN, HIGH);
    reboot_at = 0;
  }

  if(show_time) {
    /* Automatically render time */
    if(show_time != now || button_state) {
      render_clock(button_state);
      show_time = now;
    }
  }

  if (Serial.available() <= 0) return;
  int val = Serial.read();
  last_states[last_state_counter++ % (sizeof(last_states)/sizeof(last_states[0]))] = val;
  switch(state) {
  case FUNC_RESET:
    /**
     * Pyserial sometimes experience write timeouts so we
     * use a string of zeroes to resynchronize the state.
     */
    state = val;
    break;

  case FUNC_INIT_DISPLAY:
    acc = val;
    state++;
    break;
  case FUNC_INIT_DISPLAY+1:
    acc |= val << 8;
    FastLED.addLeds<NEOPIXEL, FastLED_Pin>(leds, acc);
    /* fall through */

  case FUNC_SET_RTC:
    acc = val;
    state++;
    break;
  case FUNC_SET_RTC+1:
    acc |= val << 8;
    state++;
    break;
  case FUNC_SET_RTC+2:
    acc |= val << 16;
    state++;
    break;
  case FUNC_SET_RTC+3:
    acc |= val << 24;
#ifdef TEENSYDUINO
    Teensy3Clock.set(acc); // set the RTC
    setTime(acc);
    Serial.printf("RTC synchronized: %04d-%02d-%02dT%02d:%02d:%02dZ\n", year(), month(), day(), hour(), minute(), second());
#endif
    state = FUNC_RESET;
    break;

  case FUNC_CLEAR_DISPLAY:
    for(int i = 0; i < NUM_LEDS; i++)
      leds[i].setRGB(0,0,0);
    /* fall through */

  case FUNC_SHOW_DISPLAY:
    FastLED.show();
    state = FUNC_RESET;
    break;

  case FUNC_SUSPEND_HOST:
    acc = val;
    state++;
    break;
  case FUNC_SUSPEND_HOST+1:
    acc |= val << 8;
    /* TODO: Suspend host computer */
    reboot_at = now + acc;
    if(reboot_at >= 10) {
      /* Automatically render time while host computer is offline */
      show_time = 1;
      Serial.printf("Shutting down host computer, reboot scheduled in %ds\n", reboot_at);
      /* Initiate poweroff on Raspberry Pi */
      digitalWrite(HOST_SHUTDOWN_PIN, LOW);
      delay(1);
      digitalWrite(HOST_SHUTDOWN_PIN, HIGH);
    }

    state = FUNC_RESET;
    break;

  case FUNC_AUTO_TIME:
    if(val == '\r' || val == '\n')
      show_time = !show_time; /* toggle */
    else
      show_time = val;

    /* Clear display */
    for(int i = 0; i < NUM_LEDS; i++)
      leds[i].setRGB(0,0,0);
    FastLED.show();

    Serial.printf("Automatic rendering of current time: %d\n", show_time);
    state = FUNC_RESET;
    break;

  case FUNC_PUT_PIXEL:
    acc = val;
    state++;
    break;
  case FUNC_PUT_PIXEL+1:
    acc |= val << 8;
    state++;
    break;
  case FUNC_PUT_PIXEL+2:
    color = val;
    state++;
    break;
  case FUNC_PUT_PIXEL+3:
    color |= val << 8;
    state++;
    break;
  case FUNC_PUT_PIXEL+4:
    color |= val << 16;
    leds[(acc % NUM_LEDS)].setRGB(color & 0xff, (color >> 8) & 0xff, (color >> 16) & 0xff);
    state = FUNC_RESET;
    break;

  default:
    Serial.printf("Unknown func %d with val %d, resetting\n", state, val);
    for(unsigned int i = 0; i < sizeof(last_states)/sizeof(last_states[0]) && last_state_counter - i > 0; i++)
      Serial.printf("Previous state %d: %d\n", i, last_states[(last_state_counter-i) % (sizeof(last_states)/sizeof(last_states[0]))]);
    state = FUNC_RESET;
    break;
  }
}


/* Pretty much a port of LedMatrix.xy_to_phys() */
static void put_pixel(int x, int y, int lit) {
  /** 
   * The LEDs are laid out in a long string going from north to south,
   * one step to the east, and then south to north, before the cycle
   * starts over
   */
  int cycle = 16;
  int nssn_block = x / 2;
  int phys_addr = nssn_block * 16;
  int brightness_scaler = 48;  /* use less power */

  if(x % 2)
    phys_addr += cycle - 1 - y;
  else
    phys_addr += y;

  lit &= 0xff;
  lit /= brightness_scaler;
  leds[phys_addr % NUM_LEDS].setRGB(lit, lit, lit);
}


#ifdef TEENSYDUINO
/* Wrapper function for Timelib's sync provider */
static time_t getTeensy3Time(void)
{
  return Teensy3Clock.get();
}
#endif


/* Render time as reported by the RTC */
static int clock_state = 0x2;
static void render_clock(int button_state) {
  char buf[10];
  int x_off;
  size_t len;

  if(button_state) {
    clock_state ^= 1 << (button_state-1);
    for(int i = 0; i < NUM_LEDS; i++)
      leds[i].setRGB(0,0,0);
  }

#ifdef TEENSYDUINO
  if((clock_state & 1) == 0) {
      sprintf(buf, "%02d:%02d", hour(), minute());
      if((clock_state & 2) && second() % 2)
          buf[2] = ' ';
  }
  else {
      sprintf(buf, "%02d.%02d.%02d", day(), month(), year() % 100);
  }
#else
  sprintf(buf, "00:00");
#endif

  if((clock_state & 1) == 0)
      x_off = 8 - clock_state;
  else
      x_off = 2;

  len = strlen(buf);
  for(size_t i = 0; i < len; i++) {
    unsigned char digit = buf[i];
    size_t offset;

    /* Kludge to compress colons and dots to two columns */
    if(digit == ':' || digit == '.' || digit == ' ' || (i && (buf[i-1] == ':' || buf[i-1] == '.' || buf[i-1] == ' ')))
      x_off--;

    for(offset = 0; offset < strlen(font_alphabet); offset++) {
      if(font_alphabet[offset] == digit) break;
    }

    int font_byte = (offset * font_width * font_height) / 8;
    int font_bit = (offset * font_width * font_height) % 8;
    for(int y = 0; y < font_height; y++) {
      for(int x = 0; x < font_width; x++) {
        if(font_data[font_byte] & (1<<font_bit))
          put_pixel(x_off+x, y, 255);
        else
          put_pixel(x_off+x, y, 0);

        if(++font_bit == 8) {
          font_byte++;
          font_bit = 0;
        }
      }
    }

    x_off += font_width;
  }

#ifdef TEENSYDUINO
  /* Display seconds bar */
  if(clock_state == 2) {
    int height = 1 + second() / 12;
    for(int y = 0; y < 5; y++) {
      int color = 0;
      if(y < height) color = 128;
      if(y == height-1 && second() % 2) color = 0;
      put_pixel(x_off+1, 4-y, color);
    }
  }

  /* Display weekdays */
  x_off = 2;
  int today_to_i = (weekday() + 5) % 7;
  for(int i = 0; i < 7; i++) {
    int color = i == today_to_i? 255: 64;
    put_pixel(x_off+4*i+0, 7, color);
    put_pixel(x_off+4*i+1, 7, color);
    put_pixel(x_off+4*i+2, 7, color);
  }
#endif

  FastLED.show();
}

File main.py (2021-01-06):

#!/usr/bin/env python
#
# This is a project to drive a 32x8 or 16x16 LED matrix based on the popular
# WS2812 RGB LEDs using a microcontroller running MicroPython (preferrably
# one with 4MB RAM although modules with 1MB also work).
#
#   -- noah@hack.se, 2018
#
import sys
import time
import gc
from math import ceil
from ledmatrix import LedMatrix
# This is to make sure we have a large contiguous block of RAM on devices with
# 520kB RAM after all modules and modules have been compiled and instantiated.
#
# In the weather scene, the ussl module needs a large chunk of around 1850
# bytes, and without the dummy allocation below the heap will be too
# fragmented after all the initial processing to find such a large chunk.
large_temp_chunk = bytearray(3400)

pycom_board = False
esp8266_board = False
if hasattr(sys,'implementation') and sys.implementation.name == 'micropython':
	import ujson as json
	import machine
	from network import WLAN
	from os import uname
	tmp = uname()
	if tmp.sysname == 'esp8266':
		esp8266_board = True
		from upyhal import uPyHAL as HAL
	else:
		pycom_board = True
		from pycomhal import PycomHAL as HAL
	tmp = None
	del uname
else:
	import json
	import os
	import signal
	# Kludge to allow this project to be used with a Raspberry Pi instead of
	# an MCU: see https://github.com/noahwilliamsson/lamatrix/issues/1
	try:
		# If the rpi_ws281x Python module is available, then use that...
		from raspberrypihal import RaspberryPiHAL as HAL
	except:
		# ...else assume that there's an MCU (driving the display) connected
		# to a serial port
		from arduinoserialhal import ArduinoSerialHAL as HAL

gc.collect()
from renderloop import RenderLoop


def sigint_handler(sig, frame):
	"""
	Clear display when the program is terminated by Ctrl-C or SIGTERM
	"""
	global driver
	driver.clear_display()
	driver.set_auto_time(True)
	sys.exit(0)


if __name__ == '__main__':
	f = open('config.json')
	config = json.loads(f.read())
	f.close()
	del json

	# Initialize HAL
	driver = HAL(config)
	if not esp8266_board and not pycom_board:
		# We're running on the host computer here
		ports = [
			'/dev/tty.usbmodem575711',      # Teensy 3.x on macOS
			'/dev/tty.usbserial-DQ008J7R',  # Pycom device on macOS
			'/dev/ttyUSB0',                 # Linux
			'/dev/ttyACM0',                 # Linux
		]
		for port in ports:
			if os.path.exists(port):
				config['port'] = port
				break
		# Disable automatic rendering of time
		driver.set_auto_time(False)
		# Trap Ctrl-C and service termination
		signal.signal(signal.SIGINT, sigint_handler)
		signal.signal(signal.SIGTERM, sigint_handler)

	# Initialize led matrix framebuffer on top of HAL
	display = LedMatrix(driver, config['LedMatrix'])
	driver.clear_display()

	if pycom_board:
		# We're running under MCU here
		from bootscene import BootScene
		scene = BootScene(display, config['Boot'])
		wlan = WLAN(mode=WLAN.STA)
		if not wlan.isconnected():
			print('WLAN: Scanning for networks')
			scene.render(0,0,0)
			default_ssid, default_auth = wlan.ssid(), wlan.auth()
			candidates = wlan.scan()
			for conf in config['networks']:
				nets = [candidate for candidate in candidates if candidate.ssid == conf['ssid']]
				if not nets:
					continue
				print('WLAN: Connecting to known network: {}'.format(nets[0].ssid))
				wlan.connect(nets[0].ssid, auth=(nets[0].sec, conf['password']))
				for i in range(1,40):
					scene.render(i, 0, 0)
					time.sleep(0.2)
					if wlan.isconnected():
						break
				if wlan.isconnected():
					break
		scene.render(0, 0, 0)
		if not wlan.isconnected():
			# TODO: This will only use SSID/auth settings from NVRAM during cold boots
			print('WLAN: No known networks, enabling AP with ssid={}, pwd={}'.format(default_ssid, default_auth[1]))
			wlan.init(mode=WLAN.AP, ssid=default_ssid, auth=default_auth, channel=6)
		else:
			display.clear()
			print('WLAN: Connected with IP: {}'.format(wlan.ifconfig()[0]))
			# Initialize RTC now that we're connected
			driver.set_rtc(scene)
			scene.render(0,0,0)
		scene = None
		del BootScene
	elif esp8266_board:
		pass


	# This is where it all begins
	r = RenderLoop(display, config)

	if 'Clock' in config:
		from clockscene import ClockScene
		scene = ClockScene(display, config['Clock'])
		r.add_scene(scene)
		gc.collect()

	if 'Demo' in config:
		from demoscene import DemoScene
		scene = DemoScene(display, config['Demo'])
		r.add_scene(scene)
		gc.collect()

	if 'Weather' in config:
		from weatherscene import WeatherScene
		scene = WeatherScene(display, config['Weather'])
		r.add_scene(scene)
		gc.collect()

	if 'Fire' in config:
		from firescene import FireScene
		scene = FireScene(display, config['Fire'])
		r.add_scene(scene)
		gc.collect()

	if 'Animation' in config:
		from animationscene import AnimationScene
		scene = AnimationScene(display, config['Animation'])
		r.add_scene(scene)
		gc.collect()

	# Now that we're all setup, release the large chunk
	large_temp_chunk = None

	# Render scenes forever
	while True:
		# Process input
		button_state = 0
		if pycom_board:
			# When running under MicroPython on the MCU we need to deal with
			# any input coming from the host over the serial link
			while True:
				button_state = driver.process_input()
				if driver.enable_auto_time:
					# If the host disconnected we'll hand over control to the
					# game loop which will take care of updating the display
					break
		else:
			# When running under regular Python on the host computer we need
			# to pick up any button presses sent over the serial link from
			# the Arduino firmware
			n = 0
			while True:
				# Drain output from MCU and detect button presses
				line = driver.process_input()
				if not line:
					break
				event = line.strip()
				if event == 'LEFTB_SHRT_PRESS':
					button_state = 1
				elif event == 'LEFTB_LONG_PRESS':
					button_state = 2
				else:
					print('MCU: {}'.format(event))
		r.next_frame(button_state)

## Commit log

2018-12-26 Rewrite to reduce memory usage and add more features
    In addition to the clock scene, both the animation scene and the weather
    scene should now work under MicroPython on devices with 520kBytes of RAM
    (e.g. LoPy 1, WiPy 2) after:
    - combating heap fragmentation during initialization by temporarily allocating
    a large chunk of RAM in the beginning of main.py and freeing it after all
    modules have been imported and initialized
    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
    [8x32-ledmatrix-back.scad, backsideFrame32x8.stl, lamatrix.scad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]
2021-01-06 Basic support for driving a display with rpi_ws281x
    NOTE: weatherscene.py is known to NOT work under Python 3.x due to
    an incompatibility with MicroPython's handling of strings and bytes.
    This can be easily resolved although I opted to not do this, to preserve
    compabilitity with the original code.
    To use this on a Raspberry Pi, try:
    sudo apt install -y python-pip python-requests
    sudo pip install rpi_ws281x
    Then connect the display's data line to the Raspberry Pi's GPIO 18 (PCM CLK)
    (see https://pinout.xyz/)
    References:
    - https://github.com/noahwilliamsson/lamatrix/issues/1
    - https://github.com/rpi-ws281x/rpi-ws281x-python (userspace WS281x driver)
    - https://github.com/jgarff/rp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
    [main.py, raspberrypihal.py]
2021-04-25 Some of the json files have floats not ints and structse need ints
    To address this error. Cause the images contain floats.
    Traceback (most recent call last):
    File "..\scripts\convert-animation.py", line 48, in <module>
    f.write(struct.pack('B', 255*column[color]))
    struct.error: required argument is not an integer
